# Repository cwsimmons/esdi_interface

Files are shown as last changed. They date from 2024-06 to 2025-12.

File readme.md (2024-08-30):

# A Zynq Based ESDI Disk Interface

The immediate goal of this project is to create a solution for reading data off old ESDI hard drives. At the moment it is capable of reading disk formatted by a couple of controllers, with retry logic, to create an image. More work needs to be done to increase confidence in its results.

I have made a PCB which allows me to connect a drive to my dev kit. It is an FMC based design, so unfortunately it only connects to dev boards which are over kill for this application. Nevertheless, the design files can be found under `esdi_fmc`
Eventually, I'd like to create a PCB that can accompany a cheaper (hopefully significantly) dev board than the one I'm using. In the meantime, someone with prior Zynq experience should not have much trouble moving the design to a different board.

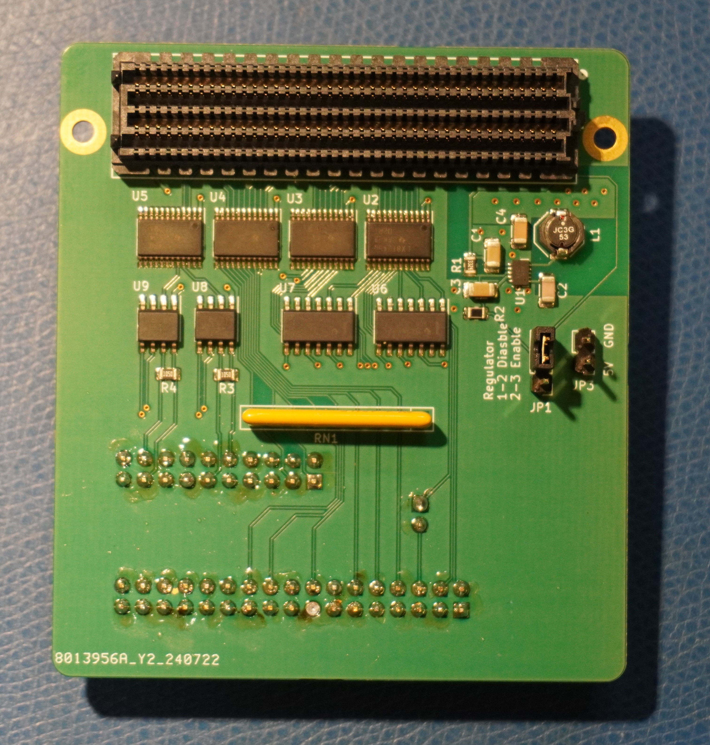
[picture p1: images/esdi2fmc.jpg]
Picture of FMC Adapter


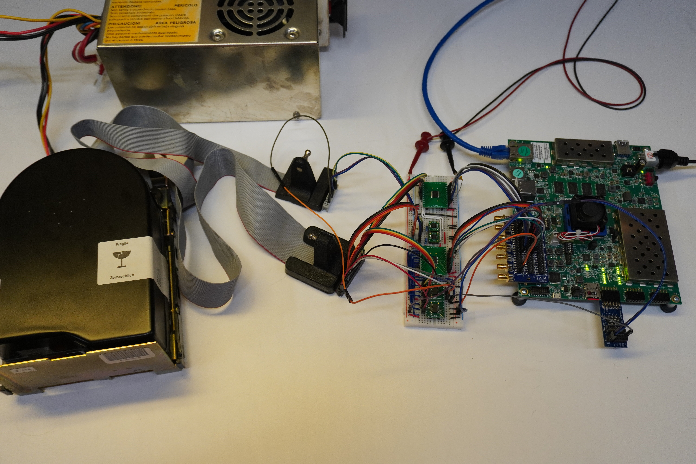
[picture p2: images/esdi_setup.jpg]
A picture of the breadboard setup


### Todo:
* Read the defect table
* Add support for more formats.
* Make sector timings more dynamic/adaptive. At the very least it needs to consider the drive's data rate.
* Figure out an abstracted way to handle relocated sectors.

## License

This program is free software: you can redistribute it and/or modify it under the terms of the GNU General Public License as published by the Free Software Foundation, either version 2 of the License, or (at your option) any later version.

This program is distributed in the hope that it will be useful, but WITHOUT ANY WARRANTY; without even the implied warranty of MERCHANTABILITY or FITNESS FOR A PARTICULAR PURPOSE. See the GNU General Public License for more details.

You should have received a copy of the GNU General Public License along with this program. If not, see <https://www.gnu.org/licenses/>.

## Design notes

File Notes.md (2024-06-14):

## Breadboard Pinout

FPGA   | FMC     | ESDI Pin  | ESDI Name
-------|---------|-----------|-------------------------
 L20   | LA02_P  |  J1,22    | READY
 L17   | LA04_P  |  J1,20    | INDEX
 J16   | LA07_P  |  J1,16    | SECTOR
 A13   | LA11_P  |  J1,12    | ATTENTION
 D16   | LA15_P  |  J1,10    | TRANSFER ACK
 D12   | LA19_P  |  J1,8     | CONFIG/STATUS DATA
 B10   | LA21_P  |  J2,17/18 | READ DATA
 B6    | LA24_P  |  J2,10/11 | READ REFERENCE CLOCK
 F16   | LA00_N  |  J1,18    | HEAD SELECT 2(1)
 K18   | LA03_N  |  J1,14    | HEAD SELECT 2(0)
 E17   | LA08_N  |  J1,34    | COMMAND DATA
 F18   | LA12_N  |  J1,32    | READ GATE
 C17   | LA16_N  |  J1,28    | DRIVE SELECT 2(1)
 E12   | LA20_N  |  J1,24    | TRANSFER REQ
 H12   | LA22_N  |  J1,4     | HEAD SELECT 2(2)
 C6    | LA25_N  |  J1,2     | HEAD SELECT 2(3)

# IBM PS/2 Controller

The last head of each cylinder is missing the last 4 sectors

byte 0    Sync = a1
byte 1    LSB of sector count
byte 2    MSB of sector count ...

flags (byte 5):
0x40 First Sector of Track
0x80 Last Sector of Track
0x20 Last head of cylinder

# IBM RT Enhanced Controller

## Address area

* byte 0 = sync = 0xfe
* byte 1 = high order cylinder?
* byte 2 = low order cylinder
* byte 3 = head
* byte 4 = logical sector

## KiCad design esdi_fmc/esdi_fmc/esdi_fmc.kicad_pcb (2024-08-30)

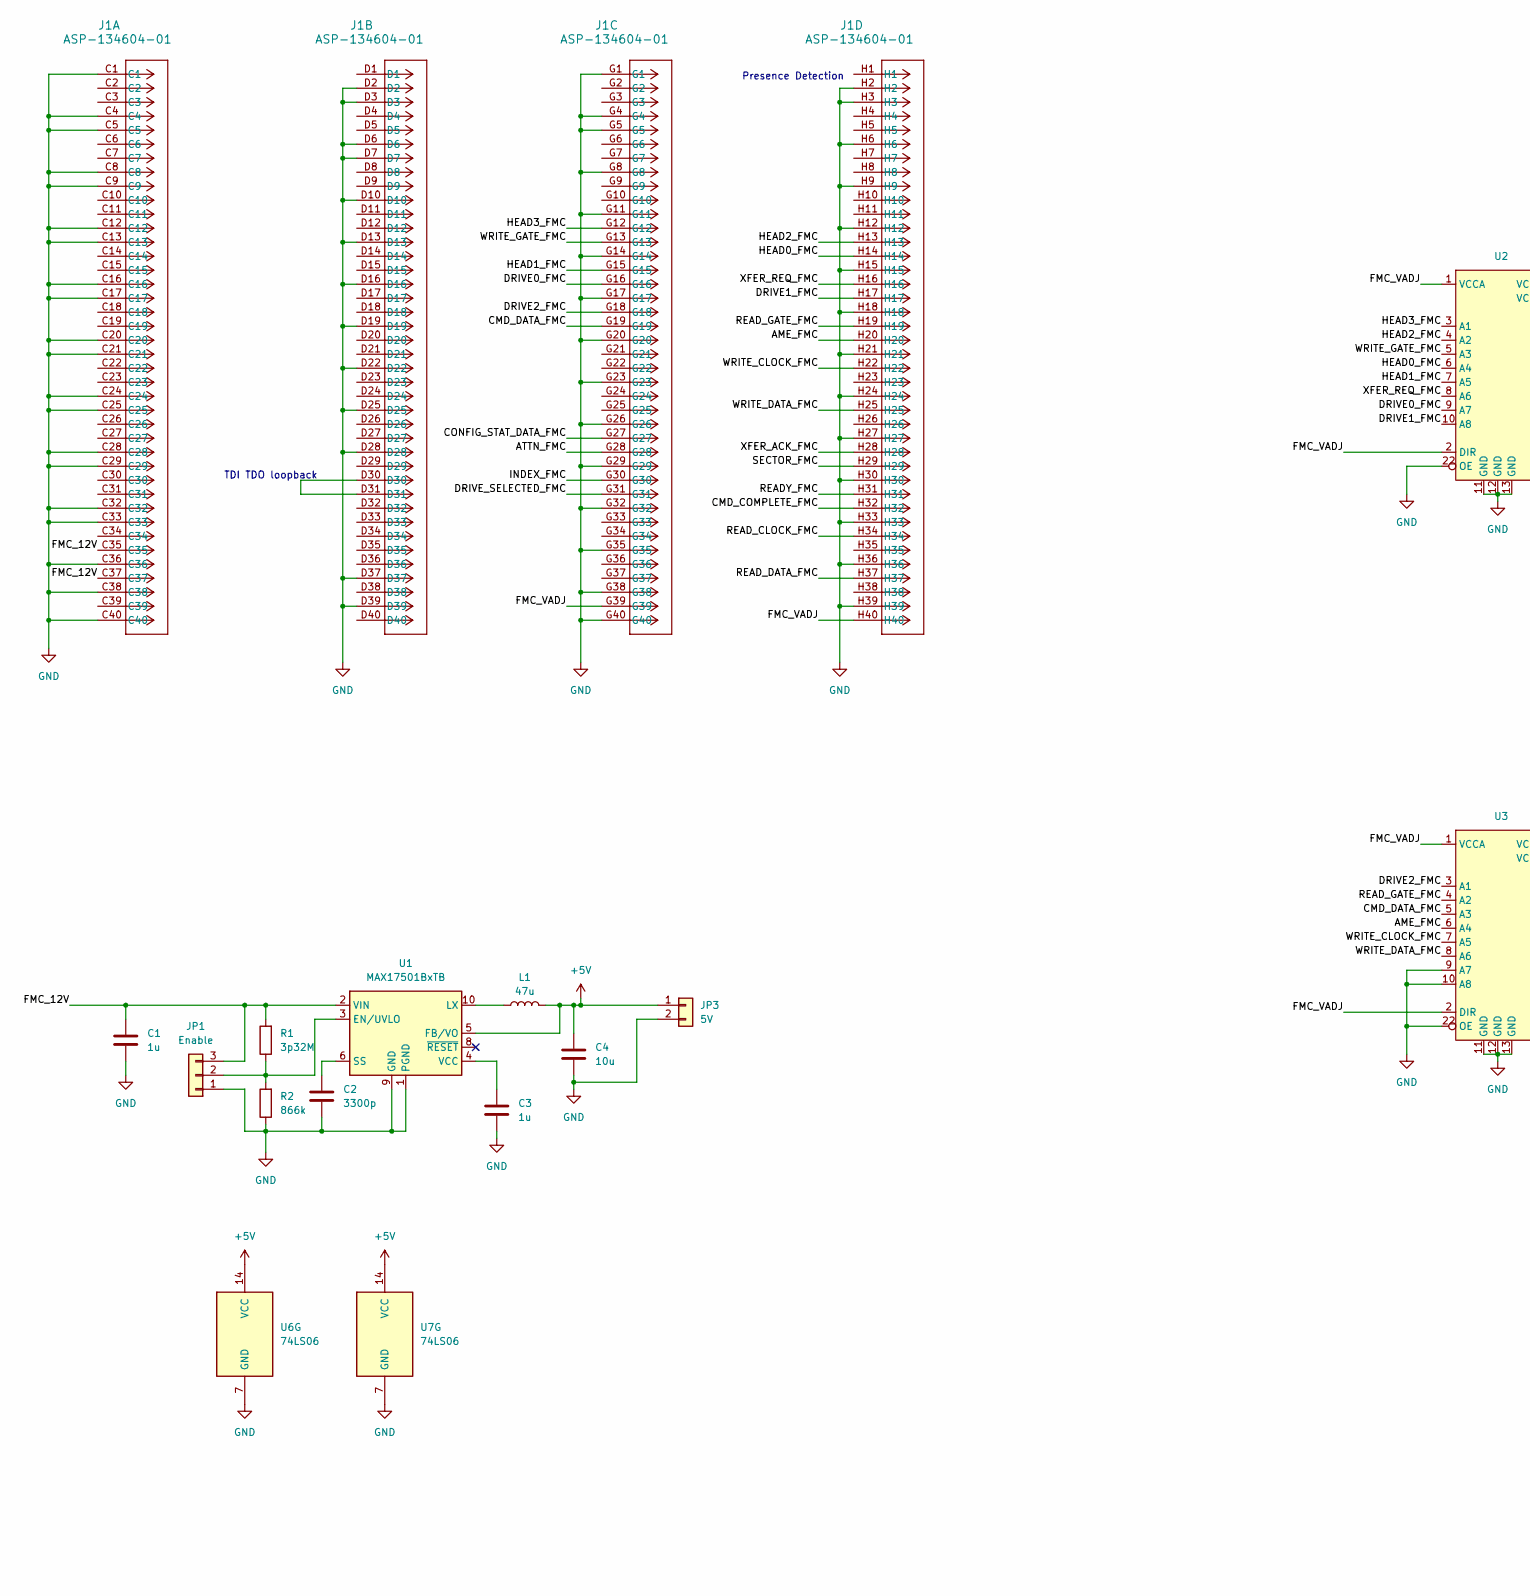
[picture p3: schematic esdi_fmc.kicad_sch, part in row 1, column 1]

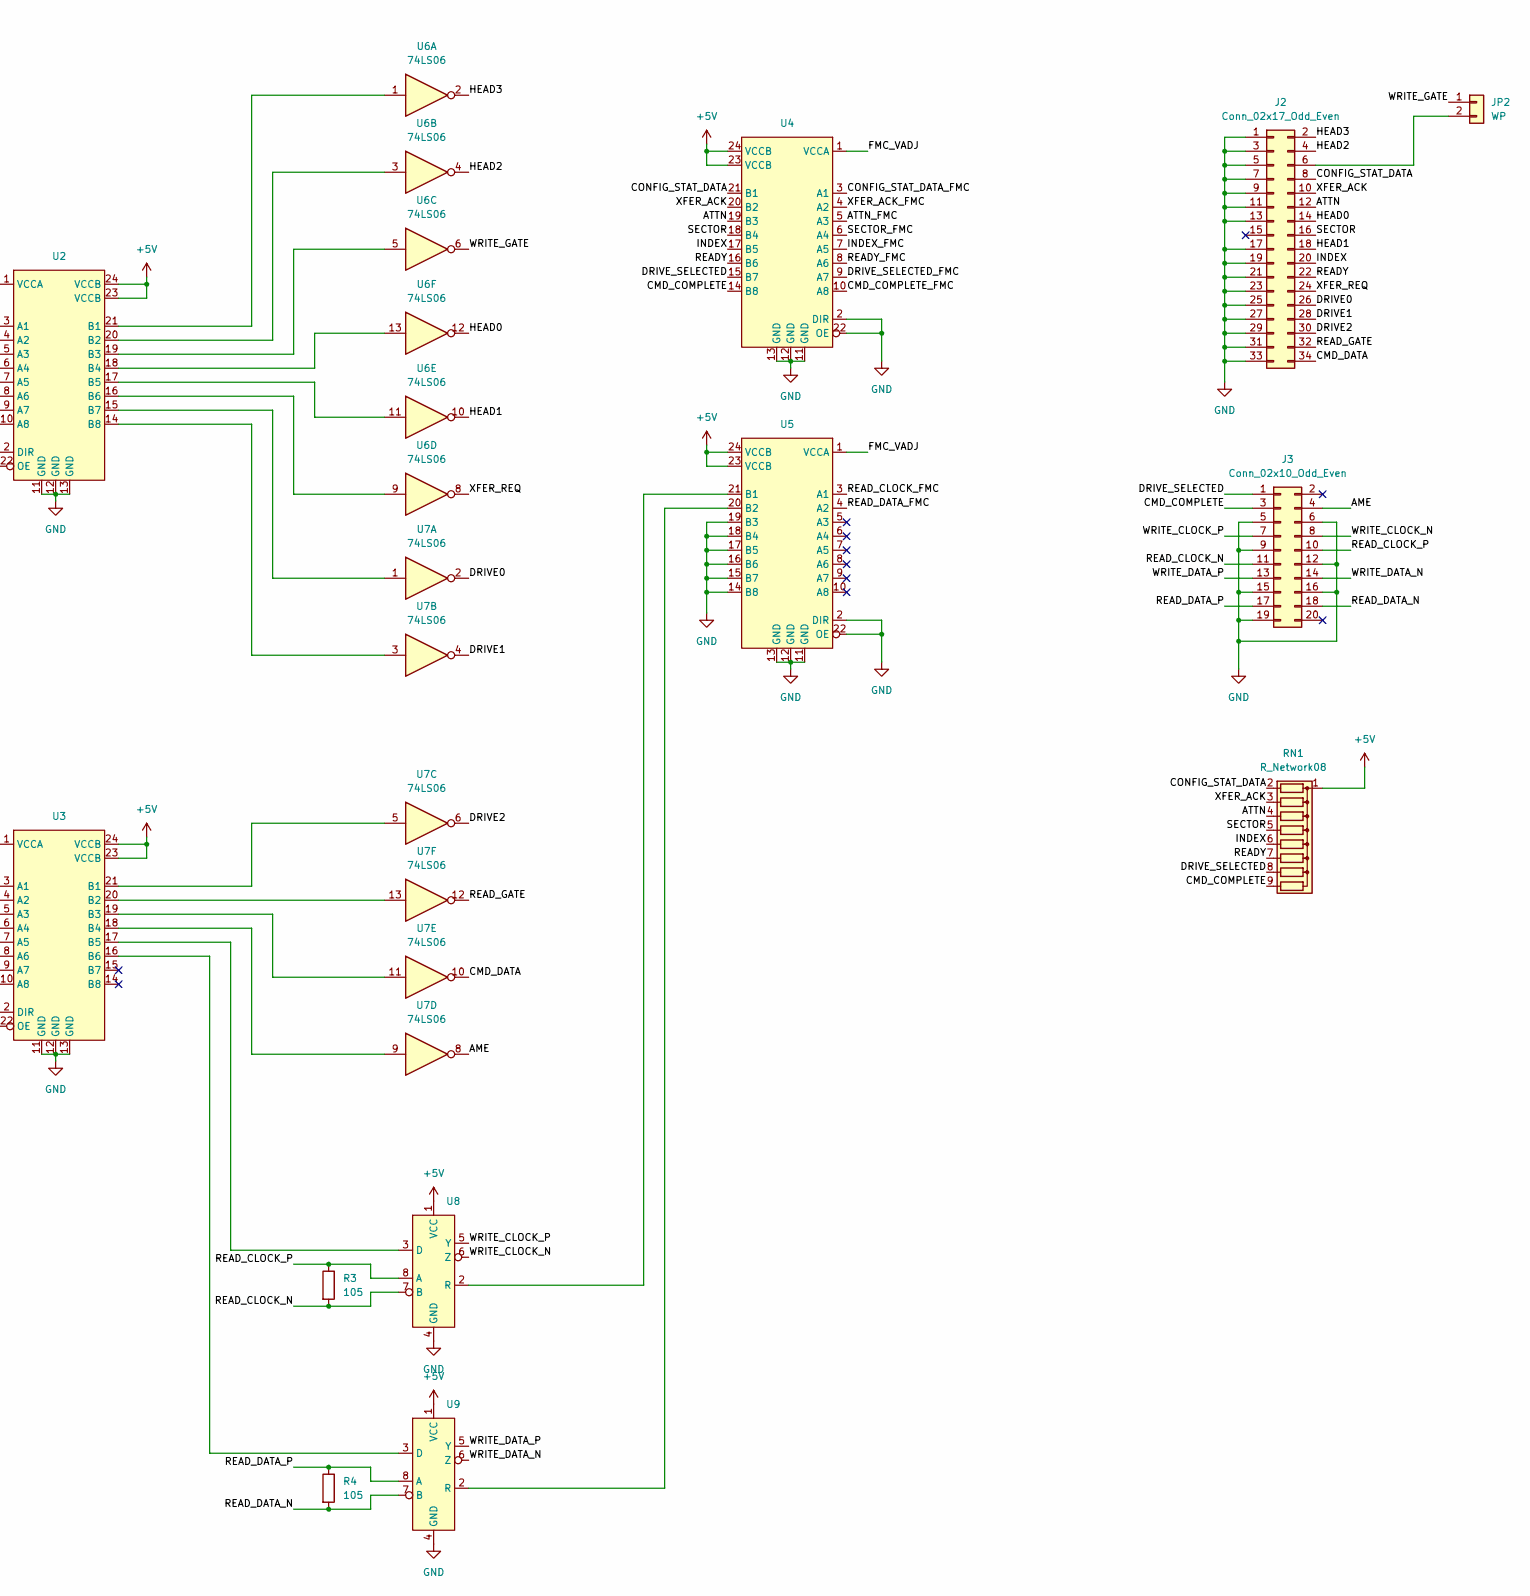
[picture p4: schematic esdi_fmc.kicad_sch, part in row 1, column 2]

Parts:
C1, C3: 1u; C_1206_3216Metric
C2: 3300p; C_1206_3216Metric
C4: 10u; C_1206_3216Metric
J1: ASP-134604-01; CONN_ASP-134604-01_SAI
J2: Conn_02x17_Odd_Even; PinHeader_2x17_P2.54mm_Vertical
J3: Conn_02x10_Odd_Even; PinHeader_2x10_P2.54mm_Vertical
JP1: Enable; PinHeader_1x03_P2.54mm_Vertical
JP2: WP; PinHeader_1x02_P2.54mm_Vertical
JP3: 5V; PinHeader_1x02_P2.54mm_Vertical
L1: 47u; Inductor_Eaton_SD53
R1: 3p32M; R_0805_2012Metric
R2: 866k; R_0805_2012Metric
R3, R4: 105; R_0805_2012Metric
RN1: R_Network08; R_Array_SIP9
U1: MAX17501BxTB; TDFN-10-1EP_2x3mm_P0.5mm_EP0.9x2mm
U2, U3, U4, U5: TSSOP-24_4.4x7.8mm_P0.65mm
U6, U7: 74LS06; SOIC-14_3.9x8.7mm_P1.27mm
U8, U9: SOIC-8_3.9x4.9mm_P1.27mm

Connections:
+5V: C4.1, JP3.1, L1.2, RN1.1 (common), U1.5 (FB/VO), U2.23 (VCCB), U2.24 (VCCB), U3.23 (VCCB), U3.24 (VCCB), U4.23 (VCCB), U4.24 (VCCB), U5.23 (VCCB), U5.24 (VCCB), U6.14 (VCC), U7.14 (VCC), U8.1 (VCC), U9.1 (VCC)
/AME: J3.4, U7.8
/AME_FMC: J1.H20, U3.6 (A4)
/ATTN: J2.12, RN1.4 (R3), U4.19 (B3)
/ATTN_FMC: J1.G28, U4.5 (A3)
/CMD_COMPLETE: J3.3, RN1.9 (R8), U4.14 (B8)
/CMD_COMPLETE_FMC: J1.H32, U4.10 (A8)
/CMD_DATA: J2.34, U7.10
/CMD_DATA_FMC: J1.G19, U3.5 (A3)
/CONFIG_STAT_DATA: J2.8, RN1.2 (R1), U4.21 (B1)
/CONFIG_STAT_DATA_FMC: J1.G27, U4.3 (A1)
/DRIVE0: J2.26, U7.2
/DRIVE0_FMC: J1.G16, U2.9 (A7)
/DRIVE1: J2.28, U7.4
/DRIVE1_FMC: J1.H17, U2.10 (A8)
/DRIVE2: J2.30, U7.6
/DRIVE2_FMC: J1.G18, U3.3 (A1)
/DRIVE_SELECTED: J3.1, RN1.8 (R7), U4.15 (B7)
/DRIVE_SELECTED_FMC: J1.G31, U4.9 (A7)
/FMC_12V: C1.1, J1.C35, J1.C37, JP1.3, R1.2, U1.2 (VIN)
/FMC_VADJ: J1.G39, J1.H40, U2.1 (VCCA), U2.2 (DIR), U3.1 (VCCA), U3.2 (DIR), U4.1 (VCCA), U5.1 (VCCA)
/HEAD0: J2.14, U6.12
/HEAD0_FMC: J1.H14, U2.6 (A4)
/HEAD1: J2.18, U6.10
/HEAD1_FMC: J1.G15, U2.7 (A5)
/HEAD2: J2.4, U6.4
/HEAD2_FMC: J1.H13, U2.4 (A2)
/HEAD3: J2.2, U6.2
/HEAD3_FMC: J1.G12, U2.3 (A1)
/INDEX: J2.20, RN1.6 (R5), U4.17 (B5)
/INDEX_FMC: J1.G30, U4.7 (A5)
/READY: J2.22, RN1.7 (R6), U4.16 (B6)
/READY_FMC: J1.H31, U4.8 (A6)
/READ_CLOCK_FMC: J1.H34, U5.3 (A1)
/READ_CLOCK_N: J3.11, R3.2, U8.7 (B)
/READ_CLOCK_P: J3.10, R3.1, U8.8 (A)
/READ_DATA_FMC: J1.H37, U5.4 (A2)
/READ_DATA_N: J3.18, R4.2, U9.7 (B)
/READ_DATA_P: J3.17, R4.1, U9.8 (A)
/READ_GATE: J2.32, U7.12
/READ_GATE_FMC: J1.H19, U3.4 (A2)
/SECTOR: J2.16, RN1.5 (R4), U4.18 (B4)
/SECTOR_FMC: J1.H29, U4.6 (A4)
/WRITE_CLOCK_FMC: J1.H22, U3.7 (A5)
/WRITE_CLOCK_N: J3.8, U8.6 (Z)
/WRITE_CLOCK_P: J3.7, U8.5 (Y)
/WRITE_DATA_FMC: J1.H25, U3.8 (A6)
/WRITE_DATA_N: J3.14, U9.6 (Z)
/WRITE_DATA_P: J3.13, U9.5 (Y)
/WRITE_GATE: JP2.1, U6.6
/WRITE_GATE_FMC: J1.G13, U2.5 (A3)
/XFER_ACK: J2.10, RN1.3 (R2), U4.20 (B2)
/XFER_ACK_FMC: J1.H28, U4.4 (A2)
/XFER_REQ: J2.24, U6.8
/XFER_REQ_FMC: J1.H16, U2.8 (A6)
GND: C1.2, C2.2, C3.2, C4.2, J1.C1, J1.C4, J1.C5, J1.C8, J1.C9, J1.C12, J1.C13, J1.C16, J1.C17, J1.C20, J1.C21, J1.C24, J1.C25, J1.C28, J1.C29, J1.C32, J1.C33, J1.C36, J1.C38, J1.C40, J1.D2, J1.D3, J1.D6, J1.D7, J1.D10, J1.D13, J1.D16, J1.D19, J1.D22, J1.D25, J1.D28, J1.D37, J1.D39, J1.G1, J1.G4, J1.G5, J1.G8, J1.G11, J1.G14, J1.G17, J1.G20, J1.G23, J1.G26, J1.G29, J1.G32, J1.G35, J1.G38, J1.G40, J1.H2, J1.H3, J1.H6, J1.H9, J1.H12, J1.H15, J1.H18, J1.H21, J1.H24, J1.H27, J1.H30, J1.H33, J1.H36, J1.H39, J2.1, J2.3, J2.5, J2.7, J2.9, J2.11, J2.13, J2.17, J2.19, J2.21, J2.23, J2.25, J2.27, J2.29, J2.31, J2.33, J3.5, J3.6, J3.9, J3.12, J3.15, J3.16, J3.19, JP1.1, JP3.2, R2.1, U1.1 (PGND), U1.9 (GND), U1.11 (GND), U2.11 (GND), U2.12 (GND), U2.13 (GND), U2.22 (OE), U3.9 (A7), U3.10 (A8), U3.11 (GND), U3.12 (GND), U3.13 (GND), U3.22 (OE), U4.2 (DIR), U4.11 (GND), U4.12 (GND), U4.13 (GND), U4.22 (OE), U5.2 (DIR), U5.11 (GND), U5.12 (GND), U5.13 (GND), U5.14 (B8), U5.15 (B7), U5.16 (B6), U5.17 (B5), U5.18 (B4), U5.19 (B3), U5.22 (OE), U6.7 (GND), U7.7 (GND), U8.4 (GND), U9.4 (GND)
unnamed: J1.D30, J1.D31
unnamed: J2.6, JP2.2
unnamed: JP1.2, R1.1, R2.2, U1.3 (EN/UVLO)
unnamed: L1.1, U1.10 (LX)
unnamed: C2.1, U1.6 (SS)
unnamed: C3.1, U1.4 (VCC)
unnamed: U2.21 (B1), U6.1
unnamed: U2.20 (B2), U6.3
unnamed: U2.19 (B3), U6.5
unnamed: U2.18 (B4), U6.13
unnamed: U2.17 (B5), U6.11
unnamed: U2.16 (B6), U6.9
unnamed: U2.15 (B7), U7.1
unnamed: U2.14 (B8), U7.3
unnamed: U3.21 (B1), U7.5
unnamed: U3.20 (B2), U7.13
unnamed: U3.19 (B3), U7.11
unnamed: U3.18 (B4), U7.9
unnamed: U3.17 (B5), U8.3 (D)
unnamed: U3.16 (B6), U9.3 (D)
unnamed: U5.21 (B1), U8.2 (R)
unnamed: U5.20 (B2), U9.2 (R)

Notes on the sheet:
TDI TDO loopback
Presence Detection

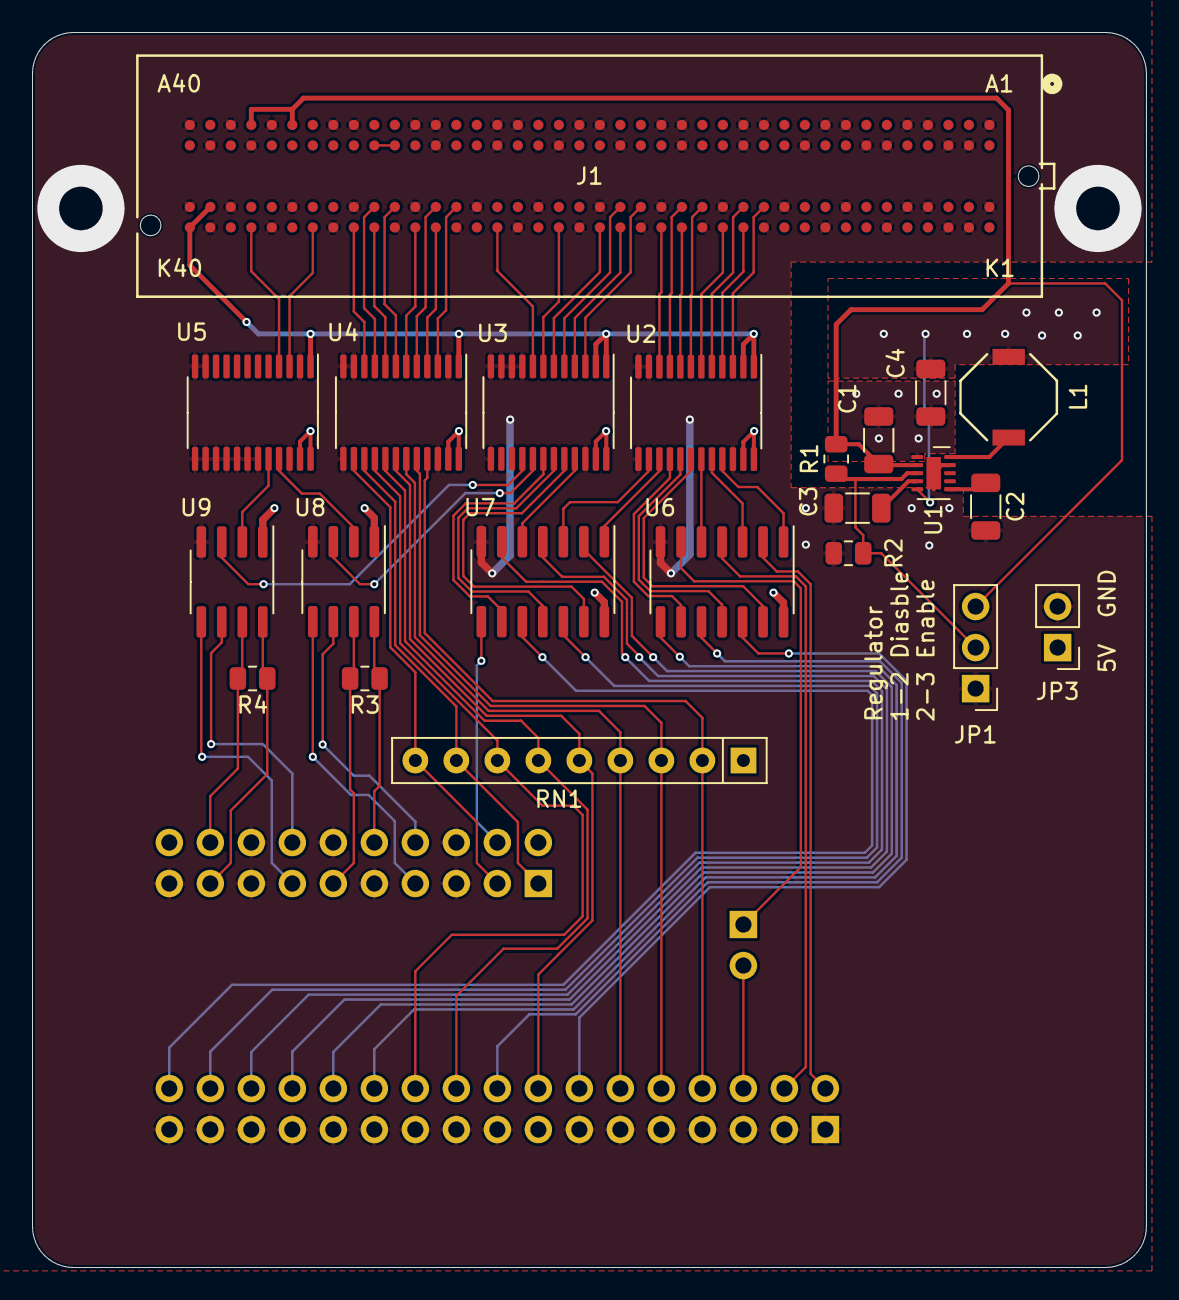
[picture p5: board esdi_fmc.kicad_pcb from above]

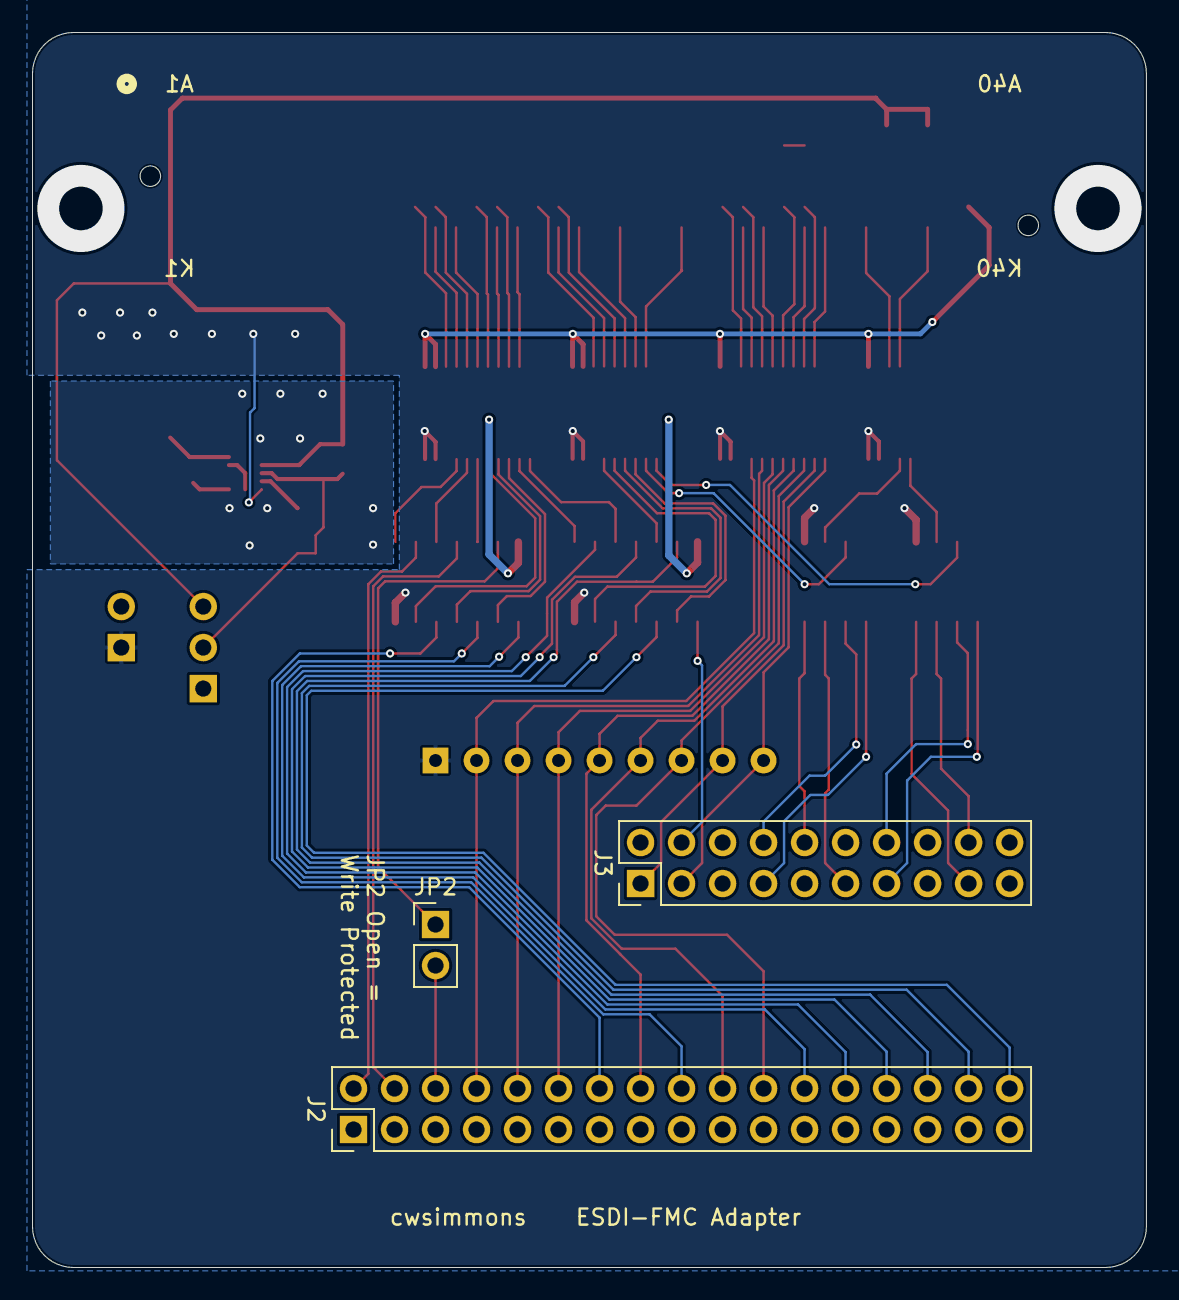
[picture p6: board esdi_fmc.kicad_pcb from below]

Board: 2 copper layers, 69.0 x 76.5 mm, 25 parts (3 on the bottom side), 78 nets.

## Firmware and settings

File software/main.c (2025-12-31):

/* 

    Copyright 2024 Christopher Simmons

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
*/

#include <stdio.h>
#include <stdint.h>
#include <stdbool.h>
#include <getopt.h>
#include <stdlib.h>
#include <string.h>
#include <strings.h>
#include <unistd.h>
#include <fcntl.h>
#include <sys/mman.h>
#include <signal.h>

#include "addresses.h"
#include "crc.h"
#include "types.h"
#include "serial_command.h"
#include "datapath.h"
#include "drive.h"
#include "util.h"
#include "controller.h"

#include "ibm_5364.h"
#include "ibm_ps2.h"
#include "ibm_rt_enhanced.h"
#include "adaptec_acb2322.h"
#include "ultrastor_12f.h"

#define EMULATION_DATA_OFFSET 1024
#define EMULATION_FILE_ALIGNMENT 16

void shutdown() {
    printf("Shutting down.\n");
    set_drive_select(0);
    datapath_stop();
}

bool stop = false;

void ctrlc(int arg) {

    stop = true;
}

bool all_sectors_accounted_for(
    int num_sectors,
    enum SectorStatus* physical_sector_statuses,
    int* expected_lbas,
    int num_expected_lbas,
    int* processed_lbas,
    int num_processed_lbas,
    bool creating_emulation_file
) {

    // Return true if either all sectors decoded without
    // error or all expected LBAs were processed

    bool all_sectors_decoded_ok = true;

    for (int i = 0; i < num_sectors; i++) {
        if (physical_sector_statuses[i] != READ_OK) {
            all_sectors_decoded_ok = false;
            break;
        }
    }

    if (all_sectors_decoded_ok)
        return true;

    if (creating_emulation_file)
        return all_sectors_decoded_ok;

    bool all_expected_are_processed = true;
    for (int i = 0; i < num_expected_lbas; i++) {
        if (array_find_value(processed_lbas, &num_processed_lbas, expected_lbas[i]) == -1) {
            all_expected_are_processed = false;
            break;
        }
    }

    return all_expected_are_processed;

}

int main(int argc, char** argv)
{
    int c;
    int option_index = 0;

    bool verbose = false;

    int drive_select = -1;
    int sector_mode = -1;
    int cylinders = -1;
    int heads = -1;
    int sectors = -1;
    int controller = -1;
    int starting_cylinder = 0;
    int max_attempts = 5;
    struct drive_parameters drive_params;
    struct drive_configuration drive_conf;
    struct emulation_header emu_header;
    uint8_t* input_sector = NULL;

    char extract_data_filename[FILENAME_MAX] = "";
    char data_crc_analysis_prefix[FILENAME_MAX] = "";
    char emulation_file[FILENAME_MAX] = "";
    char input_file[FILENAME_MAX] = "";

    char* sector_mode_options[2] = {"hard", "soft"};
    
    static struct option long_options[] = {
        {"drive",           required_argument, 0, 'd'},
        {"sector-mode",     required_argument, 0, 'm'},
        {"cylinders",       required_argument, 0, 'c'},
        {"heads",           required_argument, 0, 'h'},
        {"sectors",         required_argument, 0, 's'},
        {"verbose",         no_argument,       0,  0 },
        {"extracted-data",  required_argument, 0, 'e'},
        {"controller",      required_argument, 0, 'C'},
        {"start-cyl",       required_argument, 0, 'S'},
        {"max-attempts",    required_argument, 0, 'r'},
        {"data-crc-analysis", required_argument, 0, 1},
        {"emulation-file",  required_argument, 0,  2},
        {"emulation-input", required_argument, 0, 'i'},
        {0,                 0,                 0,  0 }
    };

    static struct esdi_controller* controllers[] = {
        &adaptec_acb2322,
        &ibm_5364,
        &ibm_ps2,
        &ibm_rt_enhanced,
        &ultrastor_12f,
        NULL
    };

    signal(SIGINT, ctrlc);

    while ((c = getopt_long(argc, argv, "d:m:c:h:s:e:C:S:r:i:", long_options, &option_index)) != -1) {

        switch (c) {
            case 0:
                verbose = true;
                break;

            case 'd':
                sscanf(optarg, "%i", &drive_select);
                break;

            case 'm':
                for (int i = 0; i < 2; i++) {
                    if (strcasecmp(sector_mode_options[i], optarg) == 0)
                        sector_mode = i;
                }
                break;

            case 'c':
                sscanf(optarg, "%i", &cylinders);
                break;

            case 'h':
                sscanf(optarg, "%i", &heads);
                break;

            case 's':
                sscanf(optarg, "%i", &sectors);
                break;

            case 'e':
                strcpy(extract_data_filename, optarg);
                break;

            case 'C':
                for (int i = 0; controllers[i] != NULL; i++) {
                    if (strcasecmp(controllers[i]->name, optarg) == 0)
                        controller = i;
                }
                break;

            case 'S':
                sscanf(optarg, "%i", &starting_cylinder);
                break;

            case 'r':
                sscanf(optarg, "%i", &max_attempts);
                break;

            case 1:
                strcpy(data_crc_analysis_prefix, optarg);
                break;

            case 2:
                strcpy(emulation_file, optarg);
                break;

            case 'i':
                strcpy(input_file, optarg);
                break;
                
            case '?':
                break;

            default:
                break;
        }
    }

    if (controller == -1) {
        printf("Unknown controller!\n");

        printf("Controller options are:\n");
        for (int i = 0; controllers[i] != NULL; i++) {
            printf("%s\n", controllers[i]->name);
        }

        exit(EXIT_FAILURE);
    }

    if (strlen(extract_data_filename) == 0) {
        printf("Filename not provided\n");
        exit(EXIT_FAILURE);
    }

    FILE* extract_fd = fopen(extract_data_filename, "wb");

    if (extract_fd == NULL) {
        printf("Failed to open extract data file for writing\n");
        exit(EXIT_FAILURE);
    }

    FILE* emulation_fd = NULL;
    if (strlen(emulation_file) != 0) {
        emulation_fd = fopen(emulation_file, "wb");

        if (emulation_fd == NULL) {
            printf("Failed to open emulation data file for writing\n");
            exit(EXIT_FAILURE);
        }
    }

    FILE* input_fd = NULL;
    if (strlen(input_file) != 0) {
        input_fd = fopen(input_file, "rb");

        if (input_fd == NULL) {
            printf("Failed to open input emulation data file for reading\n");
            exit(EXIT_FAILURE);
        }
    }

    if (input_fd == NULL) {

        if (drive_select == -1) {
            printf("Please specify the drive select number (-d)\n");
            exit(EXIT_FAILURE);
        }

        int fd = open("/dev/mem", O_RDWR | O_SYNC);
        if (fd == -1) {
            printf("Failed to open /dev/mem\n");
            exit(EXIT_FAILURE);
        }

        volatile uint32_t* mem_base = (uint32_t*) mmap(NULL, PL_BRIDGE_LENGTH, PROT_READ|PROT_WRITE, MAP_SHARED, fd, PL_BRIDGE_ADDR);
        if (mem_base == MAP_FAILED) {
            printf("Failed to mmap\n");
            exit(EXIT_FAILURE);
        }

        serial_command_base =  &mem_base[(ADDR_CMD - PL_BRIDGE_ADDR) >> 2];
        sector_timer_base =    &mem_base[(ADDR_TIMER - PL_BRIDGE_ADDR) >> 2];
        datapath_base =        &mem_base[(ADDR_READ - PL_BRIDGE_ADDR) >> 2];
        bram_base = (uint8_t*) &mem_base[(ADDR_BRAM - PL_BRIDGE_ADDR) >> 2];
        dma_base =             &mem_base[(ADDR_DMA - PL_BRIDGE_ADDR) >> 2];

        atexit(shutdown);


        set_drive_select(drive_select);

        usleep(1000);

        if (serial_command_base[4] & 0x8) {
            printf("Drive selected not asserted\n");
        } else {
            printf("Drive selected\n");
        }

        if (serial_command_base[4] & 0x1) {
            printf("Ready not asserted\n");
        } else {
            printf("Drive ready\n");
        }

        if (!(serial_command_base[4] & 0x2)) {
            printf("Attention is asserted\n");
        }


        uint16_t general_status;
        serial_query(CMD_REQSTAT, &general_status);
        printf("status = 0x%x\n", general_status);

        printf("resetting\n");
        drive_reset();

        serial_query(CMD_REQSTAT, &general_status);
        printf("status = 0x%x\n", general_status);


        // printf("head test\n");
        // set_head_select(15);
        // usleep(1000);
        // set_head_select(0);

        // serial_query(CMD_REQSTAT, &general_status);
        // printf("status = 0x%x\n", general_status);



        if (serial_query_drive_parameters(&drive_params)) {
            printf("Failed to query drive parameters\n");
            exit(EXIT_FAILURE);
        }
    } else {

        // Read drive_params from file
        size_t num_read = fread(&emu_header, sizeof(struct emulation_header), 1, input_fd);
        fseek(input_fd, emu_header.drive_configuration_offset, SEEK_SET);
        num_read = fread(&drive_conf, sizeof(struct drive_configuration), 1, input_fd);

        drive_params.is_soft_sectored = drive_conf.general_configuration[0] & 0x0001;
        drive_params.heads = drive_conf.specific_configuration[(CMD_REQCONF_MOD_NUMHEADS >> 8) - 1] & 0x00FF;
        drive_params.cylinders = drive_conf.specific_configuration[(CMD_REQCONF_MOD_NUMCYLFIXED >> 8) - 1];
        drive_params.sectors_hard = drive_conf.specific_configuration[(CMD_REQCONF_MOD_SECPERTRK >> 8) - 1] & 0x00FF;

        input_sector = (uint8_t*) malloc(emu_header.sector_size_in_image);
    }

    if (sector_mode != -1)
        drive_params.is_soft_sectored = (sector_mode == 1) ? true : false;
    if (cylinders != -1)
        drive_params.cylinders = cylinders;
    if (heads != -1)
        drive_params.heads = heads;

    if (sectors == -1) {
        if (!drive_params.is_soft_sectored)
            drive_params.sectors = drive_params.sectors_hard;
        else
            drive_params.sectors = -1;
    } else {
        drive_params.sectors = sectors;
    }

    if (max_attempts < 1 || input_fd != NULL)
        max_attempts = 1;

    printf("Drive Parameters:\n");
    printf("    Sectoring Mode: %s\n", sector_mode_options[drive_params.is_soft_sectored == 1]);
    printf("    Cylinders:      %d\n", drive_params.cylinders);
    printf("    Heads:          %d\n", drive_params.heads);
    if (drive_params.sectors == -1)
        printf("    Sectors:        TBD\n");
    else
        printf("    Sectors:        %d\n", drive_params.sectors);


    uint8_t* emulation_sector = NULL;

    if (emulation_fd != NULL) {
        if (serial_get_drive_configuration(&drive_conf)) {
            printf("Failed to query drive configuration data\n");
            exit(EXIT_FAILURE);
        }

        if (drive_conf.general_configuration[0] & 0x4) {
            printf("Creating emulation file for soft sectored disks not currently supported\n");
            exit(EXIT_FAILURE);
        }

        emu_header.file_version = 1;
        emu_header.drive_configuration_offset = sizeof(struct emulation_header);
        emu_header.data_offset = EMULATION_DATA_OFFSET;
        emu_header.cylinders = drive_params.cylinders;
        emu_header.heads = drive_params.heads;
        emu_header.sectors_per_track = drive_params.sectors;

        uint16_t ubps = drive_conf.specific_configuration[5-1];
        uint16_t bytes_needed = ubps + 1;


        emu_header.sector_size_in_image = ((bytes_needed + EMULATION_FILE_ALIGNMENT - 1) / EMULATION_FILE_ALIGNMENT) * EMULATION_FILE_ALIGNMENT;

        printf("Unformatted bytes per sector = %d (%d in emulation file)\n", ubps, emu_header.sector_size_in_image);

        fwrite(&emu_header, sizeof(struct emulation_header), 1, emulation_fd);
        fseek(emulation_fd, emu_header.drive_configuration_offset, SEEK_SET);
        fwrite(&drive_conf, sizeof(struct drive_configuration), 1, emulation_fd);

        emulation_sector = (uint8_t*) malloc(emu_header.sector_size_in_image);

        if (emulation_sector == NULL) {
            printf("Out of memory!\n");
            exit(EXIT_FAILURE);
        }

    }

    struct esdi_controller* controller_params = controllers[controller];

    int allocated_sectors = (drive_params.sectors > 0) ? drive_params.sectors : 128;

    int physical_sectors[128];
    int expected_lbas[128];
    enum SectorStatus physical_sector_statuses[128];
    int processed_lbas[128];

    int num_processed_lbas;

    bool reset_recommended = false;

    struct raw_sector* raw_sectors = (struct raw_sector*) malloc(sizeof(struct raw_sector) * allocated_sectors);
    struct processed_sector* processed_sectors = (struct processed_sector*) malloc(sizeof(struct processed_sector) * allocated_sectors);

    if (raw_sectors == NULL)
        printf("Out of memory!\n");

    for (int i = 0; i < allocated_sectors; i++) {
        raw_sectors[i].address_area = (uint8_t*) malloc(sizeof(uint8_t) * controller_params->addr_area_length);
        if (raw_sectors[i].address_area == NULL) printf("Out of memory!\n");

        raw_sectors[i].data_area = (uint8_t*) malloc(sizeof(uint8_t) * controller_params->data_area_length);
        if (raw_sectors[i].data_area == NULL) printf("Out of memory!\n");

        processed_sectors[i].data = (uint8_t*) malloc(sizeof(uint8_t) * controller_params->data_area_length);
        if (processed_sectors[i].data == NULL) printf("Out of memory!\n");
    }

    if (drive_params.sectors == -1) {
        printf("Discovering number of sectors not currently supported.\n");
        exit(EXIT_FAILURE);
    }

    // I thought there might be time when we don't want to read all
    // of the sectors on the track. Could probably be removed.
    for (int i = 0; i < drive_params.sectors; i++) {
        physical_sectors[i] = i;
    }

    if (input_fd == NULL) {
        datapath_sector_timer_reset();
        datapath_sector_timer_set_enable(true);
        usleep(100000);
        printf("nummber of sector seen by interface = %d\n", sector_timer_base[7]);
        datapath_sector_timer_set_enable(false);

        datapath_configure(&drive_params, controller_params);
        datapath_start();

        flush_fifo();
        reset_dma();
    }

    for (int j = starting_cylinder; (j < drive_params.cylinders) && !stop; j++) {

        if (input_fd == NULL) {
            drive_seek(j);
            usleep(100000);
        }

        printf("At cyl %d\n", j);

        for (int k = 0; (k < drive_params.heads) && !stop; k++) {

            if (input_fd == NULL) {
                set_head_select(k);
                usleep(10000);
            }

            for (int i = 0; i < drive_params.sectors; i++) {
                physical_sector_statuses[i] = UNREAD;
            }

            // Get the LBAs that we expect on this track
            int num_expected_lbas = controller_params->get_expected_lbas(
                &drive_params,
                j,
                k,
                expected_lbas    
            );

            num_processed_lbas = 0;
            int attempt = 0;

            // Keep trying until we have all of the LBAs we expect
            while (
                (attempt < max_attempts) &&
                !all_sectors_accounted_for(
                    drive_params.sectors,
                    physical_sector_statuses,
                    expected_lbas,
                    num_expected_lbas,
                    processed_lbas,
                    num_processed_lbas,
                    emulation_fd != NULL
                ) &&
                !stop
            ) {

                if (attempt > 0) {
                    int rem = num_expected_lbas - num_processed_lbas;
                    printf(
                        "Starting Attempt #%d on [%d,%d] to get %d sector%s\n",
                        attempt + 1, j, k, rem, (rem > 1) ? "s" : ""
                    );
                }

                if (reset_recommended && input_fd == NULL) {
                    printf("Resetting datapath\n");
                    reset_dma();
                    flush_fifo();
                    reset_dma();
                    reset_recommended = false;
                }

                // Read all sectors on the track
                if (input_fd == NULL) {
                    reset_recommended = read_track_sg(drive_params.sectors, physical_sectors, raw_sectors);
                } else {

                    

                    // read_track_from_emulation_file(j, k, drive_params.sectors, physical_sectors, raw_sectors);
                    for (int i = 0; i < drive_params.sectors; i++) {
                        raw_sectors[i].status = -1;
                        raw_sectors[i].address_read_ok = false;
                        raw_sectors[i].data_read_ok = false;
                        fseek(
                            input_fd,
                            emu_header.data_offset + (((((j * emu_header.heads) + k) * emu_header.sectors_per_track) + physical_sectors[i]) * emu_header.sector_size_in_image),
                            SEEK_SET
                        );
                        fread(input_sector, sizeof(uint8_t), emu_header.sector_size_in_image, input_fd);

                        if (input_sector[0] != physical_sectors[i]) {
                            printf("Sector missplaced! (found 0x%.2x, should be 0x%.2x)\n", input_sector[0], physical_sectors[i]);
                        }
                        int offset, bit;
                        int address_area_start = controller_params->addr_area_assert / 10 / 8 + 1;
                        int address_area_end = controller_params->addr_area_deassert / 10 / 8 + 2;
                        if (!findbyte(&input_sector[address_area_start], address_area_end - address_area_start, controller_params->addr_area_sync_byte, &offset, &bit)) {
                            // Can't find sync byte
                            raw_sectors[i].status = -3;
                            // hex_print(&input_sector[1], emu_header.sector_size_in_image - 1);
                            continue;
                        }
                        if ((offset + (bit ? 1 : 0) + controller_params->addr_area_length) > address_area_end - address_area_start) {
                            // Not enough data after the sync byte
                            raw_sectors[i].status = -4;
                            continue;
                        }

                        raw_sectors[i].address_start_location = (controller_params->addr_area_assert / 10) + (offset * 8) + bit;

                        copy_buff_start_at(raw_sectors[i].address_area, &input_sector[address_area_start], offset + (bit ? 1 : 0) + controller_params->addr_area_length, offset, bit);
                        // hex_print(raw_sectors[i].address_area, dp_controller_info->addr_area_length);
                        raw_sectors[i].address_read_ok = true;

                        int data_area_start = controller_params->data_area_assert / 10 / 8 + 1;
                        int data_area_end = controller_params->data_area_deassert / 10 / 8 + 2;
                        if (!findbyte(&input_sector[data_area_start], data_area_end - data_area_start, controller_params->data_area_sync_byte, &offset, &bit)) {
                            // Can't find sync byte
                            raw_sectors[i].status = -6;
                            continue;
                        }
                        if ((offset + (bit ? 1 : 0) + controller_params->data_area_length) > data_area_end - data_area_start) {
                            // Not enough data after the sync byte
                            raw_sectors[i].status = -7;
                            continue;
                        }

                        raw_sectors[i].data_start_location = (controller_params->data_area_assert / 10) + (offset * 8) + bit;

                        copy_buff_start_at(raw_sectors[i].data_area, &input_sector[data_area_start], offset + (bit ? 1 : 0) + controller_params->data_area_length, offset, bit);
                        // hex_print(raw_sectors[i].address_area, dp_controller_info->addr_area_length);
                        raw_sectors[i].data_read_ok = true;

                    }
                }

                // Process the sectors
                for (int i = 0; i < drive_params.sectors; i++) {
                    
                    raw_sectors[i].cylinder = j;
                    raw_sectors[i].head = k;
                    raw_sectors[i].physical_sector = physical_sectors[i];

                    // Move on if there was a problem reading this sector
                    if (raw_sectors[i].status) {
                        // If we didn't even manage to get the address area then we got nothing, move on...
                        if (!raw_sectors[i].address_read_ok) {
                            printf("Read error on [%d,%d,%d] = %d\n", j, k, physical_sectors[i], raw_sectors[i].status);
                            continue;
                        }
                    }

                    // The point of this block is to aid in determining the data crc.
                    // Since I don't know the if the sector is good,
                    // I just have to write the first one.
                    if ((strlen(data_crc_analysis_prefix) != 0) && (attempt == 0)) {
                        char analysis_filename[FILENAME_MAX];
                        snprintf(analysis_filename, FILENAME_MAX, "%s_%d_%d_%d.bin", data_crc_analysis_prefix, j, k, physical_sectors[i]);
                        FILE* analysis_fd = fopen(analysis_filename, "wb");
                        if (analysis_fd != NULL) {
                            fwrite(raw_sectors[i].data_area, sizeof(uint8_t), controller_params->data_area_length, analysis_fd);
                        } else {
                            printf("Could not open %s for writting\n", analysis_filename);
                        }
                    }
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

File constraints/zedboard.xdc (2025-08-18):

set_property PACKAGE_PIN T22 [get_ports {leds[0]}];  # "LD0"
set_property PACKAGE_PIN T21 [get_ports {leds[1]}];  # "LD1"
set_property PACKAGE_PIN U22 [get_ports {leds[2]}];  # "LD2"
set_property PACKAGE_PIN U21 [get_ports {leds[3]}];  # "LD3"

set_property PACKAGE_PIN T17 [get_ports {esdi_head_select[0]}];  # "FMC-LA07_N"
set_property PACKAGE_PIN T16 [get_ports {esdi_head_select[2]}];  # "FMC-LA07_P"
set_property PACKAGE_PIN J21 [get_ports {esdi_head_select[3]}];  # "FMC-LA08_P"
set_property PACKAGE_PIN N18 [get_ports {esdi_drive_select[1]}];  # "FMC-LA11_N"
set_property PACKAGE_PIN N17 [get_ports {esdi_transfer_req}];  # "FMC-LA11_P"
set_property PACKAGE_PIN P21 [get_ports {esdi_drive_select[0]}];  # "FMC-LA12_N"
set_property PACKAGE_PIN P20 [get_ports {esdi_head_select[1]}];  # "FMC-LA12_P"
set_property PACKAGE_PIN J17 [get_ports {esdi_address_mark_enable}];  # "FMC-LA15_N"
set_property PACKAGE_PIN J16 [get_ports {esdi_read_gate}];  # "FMC-LA15_P"
set_property PACKAGE_PIN K21 [get_ports {esdi_command_data}];  # "FMC-LA16_N"
set_property PACKAGE_PIN J20 [get_ports {esdi_drive_select[2]}];  # "FMC-LA16_P"
set_property PACKAGE_PIN A19 [get_ports {esdi_sector}];  # "FMC-LA24_N"
set_property PACKAGE_PIN A18 [get_ports {esdi_transfer_ack}];  # "FMC-LA24_P"
set_property PACKAGE_PIN C22 [get_ports {esdi_attention}];  # "FMC-LA25_N"
set_property PACKAGE_PIN D22 [get_ports {esdi_confstat_data}];  # "FMC-LA25_P"
set_property PACKAGE_PIN A17 [get_ports {esdi_command_complete}];  # "FMC-LA28_N"
set_property PACKAGE_PIN A16 [get_ports {esdi_ready}];  # "FMC-LA28_P"
set_property PACKAGE_PIN C18 [get_ports {esdi_drive_selected}];  # "FMC-LA29_N"
set_property PACKAGE_PIN C17 [get_ports {esdi_index}];  # "FMC-LA29_P"
set_property PACKAGE_PIN C15 [get_ports {esdi_read_clock}];  # "FMC-LA30_P"
set_property PACKAGE_PIN A21 [get_ports {esdi_read_data}];  # "FMC-LA32_P"



# ----------------------------------------------------------------------------
# IOSTANDARD Constraints
#
# Note that these IOSTANDARD constraints are applied to all IOs currently
# assigned within an I/O bank.  If these IOSTANDARD constraints are 
# evaluated prior to other PACKAGE_PIN constraints being applied, then 
# the IOSTANDARD specified will likely not be applied properly to those 
# pins.  Therefore, bank wide IOSTANDARD constraints should be placed 
# within the XDC file in a location that is evaluated AFTER all 
# PACKAGE_PIN constraints within the target bank have been evaluated.
#
# Un-comment one or more of the following IOSTANDARD constraints according to
# the bank pin assignments that are required within a design.
# ---------------------------------------------------------------------------- 

# Note that the bank voltage for IO Bank 33 is fixed to 3.3V on ZedBoard. 
set_property IOSTANDARD LVCMOS33 [get_ports -of_objects [get_iobanks 33]];

# Set the bank voltage for IO Bank 34 to 1.8V by default.
# set_property IOSTANDARD LVCMOS33 [get_ports -of_objects [get_iobanks 34]];
set_property IOSTANDARD LVCMOS25 [get_ports -of_objects [get_iobanks 34]];
# set_property IOSTANDARD LVCMOS18 [get_ports -of_objects [get_iobanks 34]];

# Set the bank voltage for IO Bank 35 to 1.8V by default.
# set_property IOSTANDARD LVCMOS33 [get_ports -of_objects [get_iobanks 35]];
set_property IOSTANDARD LVCMOS25 [get_ports -of_objects [get_iobanks 35]];
# set_property IOSTANDARD LVCMOS18 [get_ports -of_objects [get_iobanks 35]];

# Note that the bank voltage for IO Bank 13 is fixed to 3.3V on ZedBoard. 
set_property IOSTANDARD LVCMOS33 [get_ports -of_objects [get_iobanks 13]];

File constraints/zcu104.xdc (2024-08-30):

# Copyright 2024 Christopher Simmons

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

set_property PACKAGE_PIN D5       [get_ports "leds[0]"];
set_property IOSTANDARD LVCMOS33  [get_ports "leds[0]"];
set_property PACKAGE_PIN D6       [get_ports "leds[1]"];
set_property IOSTANDARD LVCMOS33  [get_ports "leds[1]"];
set_property PACKAGE_PIN A5       [get_ports "leds[2]"];
set_property IOSTANDARD LVCMOS33  [get_ports "leds[2]"];
set_property PACKAGE_PIN B5       [get_ports "leds[3]"];
set_property IOSTANDARD LVCMOS33  [get_ports "leds[3]"];

## FMC Row H
set_property PACKAGE_PIN J16      [get_ports "esdi_head_select[2]"]; # FMC_LPC_LA07_P
set_property IOSTANDARD  LVCMOS12 [get_ports "esdi_head_select[2]"]; # FMC_LPC_LA07_P
set_property PACKAGE_PIN J15      [get_ports "esdi_head_select[0]"]; # FMC_LPC_LA07_N
set_property IOSTANDARD  LVCMOS12 [get_ports "esdi_head_select[0]"]; # FMC_LPC_LA07_N
set_property PACKAGE_PIN A13      [get_ports "esdi_transfer_req"]; # FMC_LPC_LA11_P
set_property IOSTANDARD  LVCMOS12 [get_ports "esdi_transfer_req"]; # FMC_LPC_LA11_P
set_property PACKAGE_PIN A12      [get_ports "esdi_drive_select[1]"]; # FMC_LPC_LA11_N
set_property IOSTANDARD  LVCMOS12 [get_ports "esdi_drive_select[1]"]; # FMC_LPC_LA11_N
set_property PACKAGE_PIN D16      [get_ports "esdi_read_gate"]; # FMC_LPC_LA15_P
set_property IOSTANDARD  LVCMOS12 [get_ports "esdi_read_gate"]; # FMC_LPC_LA15_P
set_property PACKAGE_PIN C16      [get_ports "esdi_address_mark_enable"]; # FMC_LPC_LA15_N
set_property IOSTANDARD  LVCMOS12 [get_ports "esdi_address_mark_enable"]; # FMC_LPC_LA15_N
# set_property PACKAGE_PIN D12      [get_ports ""]; # FMC_LPC_LA19_P   Write Clock
# set_property IOSTANDARD  LVCMOS12 [get_ports ""]; # FMC_LPC_LA19_P


# set_property PACKAGE_PIN B10      [get_ports ""]; # FMC_LPC_LA21_P   Write Data
# set_property IOSTANDARD  LVCMOS12 [get_ports ""]; # FMC_LPC_LA21_P


set_property PACKAGE_PIN B6       [get_ports "esdi_transfer_ack"]; # FMC_LPC_LA24_P
set_property IOSTANDARD  LVCMOS12 [get_ports "esdi_transfer_ack"]; # FMC_LPC_LA24_P
set_property PACKAGE_PIN A6       [get_ports "esdi_sector"]; # FMC_LPC_LA24_N
set_property IOSTANDARD  LVCMOS12 [get_ports "esdi_sector"]; # FMC_LPC_LA24_N
set_property PACKAGE_PIN M13      [get_ports "esdi_ready"]; # FMC_LPC_LA28_P
set_property IOSTANDARD  LVCMOS12 [get_ports "esdi_ready"]; # FMC_LPC_LA28_P
set_property PACKAGE_PIN L13      [get_ports "esdi_command_complete"]; # FMC_LPC_LA28_N
set_property IOSTANDARD  LVCMOS12 [get_ports "esdi_command_complete"]; # FMC_LPC_LA28_N
set_property PACKAGE_PIN E9       [get_ports "esdi_read_clock"]; # FMC_LPC_LA30_P
set_property IOSTANDARD  LVCMOS12 [get_ports "esdi_read_clock"]; # FMC_LPC_LA30_P


set_property PACKAGE_PIN F8       [get_ports "esdi_read_data"]; # FMC_LPC_LA32_P
set_property IOSTANDARD  LVCMOS12 [get_ports "esdi_read_data"]; # FMC_LPC_LA32_P


## FMC Row G
set_property PACKAGE_PIN E18      [get_ports "esdi_head_select[3]"]; # FMC_LPC_LA08_P
set_property IOSTANDARD  LVCMOS12 [get_ports "esdi_head_select[3]"]; # FMC_LPC_LA08_P
# set_property PACKAGE_PIN E17      [get_ports ""]; # FMC_LPC_LA08_N   Write Gate
# set_property IOSTANDARD  LVCMOS12 [get_ports ""]; # FMC_LPC_LA08_N
set_property PACKAGE_PIN G18      [get_ports "esdi_head_select[1]"]; # FMC_LPC_LA12_P
set_property IOSTANDARD  LVCMOS12 [get_ports "esdi_head_select[1]"]; # FMC_LPC_LA12_P
set_property PACKAGE_PIN F18      [get_ports "esdi_drive_select[0]"]; # FMC_LPC_LA12_N
set_property IOSTANDARD  LVCMOS12 [get_ports "esdi_drive_select[0]"]; # FMC_LPC_LA12_N
set_property PACKAGE_PIN D17      [get_ports "esdi_drive_select[2]"]; # FMC_LPC_LA16_P
set_property IOSTANDARD  LVCMOS12 [get_ports "esdi_drive_select[2]"]; # FMC_LPC_LA16_P
set_property PACKAGE_PIN C17      [get_ports "esdi_command_data"]; # FMC_LPC_LA16_N
set_property IOSTANDARD  LVCMOS12 [get_ports "esdi_command_data"]; # FMC_LPC_LA16_N
set_property PACKAGE_PIN C7       [get_ports "esdi_confstat_data"]; # FMC_LPC_LA25_P
set_property IOSTANDARD  LVCMOS12 [get_ports "esdi_confstat_data"]; # FMC_LPC_LA25_P
set_property PACKAGE_PIN C6       [get_ports "esdi_attention"]; # FMC_LPC_LA25_N
set_property IOSTANDARD  LVCMOS12 [get_ports "esdi_attention"]; # FMC_LPC_LA25_N
set_property PACKAGE_PIN K10      [get_ports "esdi_index"]; # FMC_LPC_LA29_P
set_property IOSTANDARD  LVCMOS12 [get_ports "esdi_index"]; # FMC_LPC_LA29_P
set_property PACKAGE_PIN J10      [get_ports "esdi_drive_selected"]; # FMC_LPC_LA29_N
set_property IOSTANDARD  LVCMOS12 [get_ports "esdi_drive_selected"]; # FMC_LPC_LA29_N

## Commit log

2024-03-12 First cut at Rx datapath
2024-03-15 Add rx datapath and dma to BD
2024-06-25 Configure DMA for scatter/gather, increase BRAM
2024-06-25 Update software to use scatter/gather DMA
2024-07-02 Sector Timer: Add filter and fix bug where we could think we reached a sector even though we missed the start of it
2024-07-02 Fix the DMA reset function and add a way to clear the AXI Stream FIFO
    [main.c]
2024-08-06 Separately keep track of whether the address/data areas were read from the disk, that way we can process an address even if the data was bad
2024-08-30 Add KiCad for FMC Adpater
    [esdi_fmc-B_Cu.gbl, esdi_fmc-B_Mask.gbs, esdi_fmc-B_Silkscreen.gbo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]
2024-10-18 Add logic where the software resets the DMA when it appears that the fifo overflowed
    [main.c]
2024-10-18 Fix logic for determing if additional attempts are needed
    [main.c]
2024-10-18 Bug fix for controllers which have different sized CRC/ECC in the data area
    [main.c]
2025-05-18 * Add timeouts wherever needed * Make DMA reset actually work * Move back data area in BRAM so that we can fit more than 128 DMA descriptors * Correct issues with 5364 code (0 based sector numbers an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
    [main.c]
